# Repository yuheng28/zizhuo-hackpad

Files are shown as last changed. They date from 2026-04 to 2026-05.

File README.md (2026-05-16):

# ZizhuoPad

<p align="center">
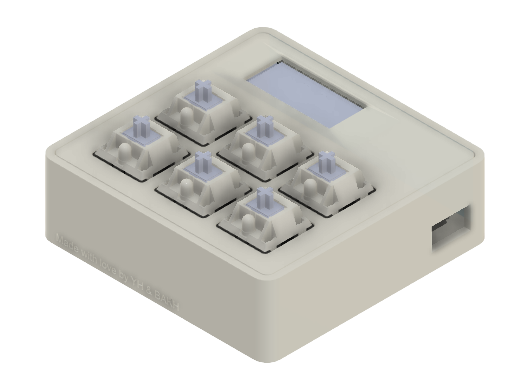
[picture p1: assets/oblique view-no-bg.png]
  
</p>

## Overview

ZizhuoPad is a custom mechanical macropad with 6 keys and an OLED display.

It is designed to allow for easy hotswapping of the switches, and (maybe not as easy) key mapping modifications.

## Rationale

This is a project to build a custom mechanical macropad. The purpose of this project is to create a birthday gift for my friend, after whom this project is named.

As a technical challenge, I opted to write the firmware using AVR-C, instead of using Arduino or QMK. The PCB was designed using KiCAD, and the case was designed using Fusion 360.

## Hardware Summary

### Electronics
- Microcontroller: SparkFun Pro Micro (ATmega32U4)
- OLED Display: 128x32 pixel display
- Switches: 6 hotswappable mechanical switches (Akko Piano Switches)
- Connector: USB-C

### Case
- Material: PETG
- Infill: 75%
- Walls: 10 for Case, 5 for Lid
- Layer Height: 0.2mm

## Modifying the Software

In the `firmware` directory, a Microchip Studio project is included. You can open the `.atsln` file in Microchip Studio to build the firmware.

The firmware uses the LUFA library to implement USB HID functionality. The project was first developed using the LUFA library's keyboard example, so as to have the build environment set up and working. Then, the code was modified to implement the desired functionality for the macropad.

However, since these are all in the project files, the build environment is already set up and working.

To modify the key mappings, lines 292-325 in Keyboard.c can be modified by replacing the keycode macros with the appropriate keycodes from LUFA's HID usage tables.

To modify the animation on the OLED display, the lines 65-135 in OLED.c can be modified with the appropriate bytes to display the desired animation. The OLED display has a resolution of 128x32 pixel display. To generate the byte array for the animation, use [Javl's image2cpp tool](https://javl.github.io/image2cpp/). The relevant settings for the tool are:
- Canvas Size: 128x32
- Orientation: Vertical
- Invert pixels: Yes (alternatively, line 191 in Keyboard.c can be commented to invert the pixels)

The other settings can be left as their default values. The generated byte array can then be copied into lines 292-325 in Keyboard.c.

After building the firmware, the resulting `Keyboard.hex` file can be flashed to the ATmega32U4 microcontroller using avrdude.

To flash the microcontroller, it needs to first be put into bootloader mode. This can be done by shorting the reset pin to ground. For approximately 8 seconds after doing this, the microcontroller will be in bootloader mode and can be flashed using avrdude.

## Project Pictures

<p align="center">
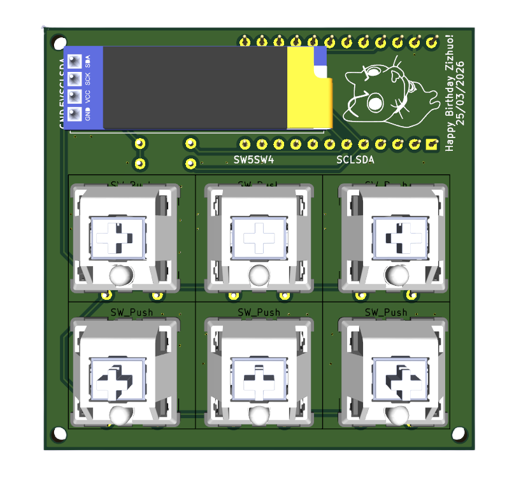
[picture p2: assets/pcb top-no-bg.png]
  
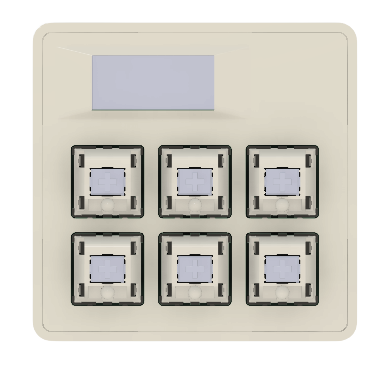
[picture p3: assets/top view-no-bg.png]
  
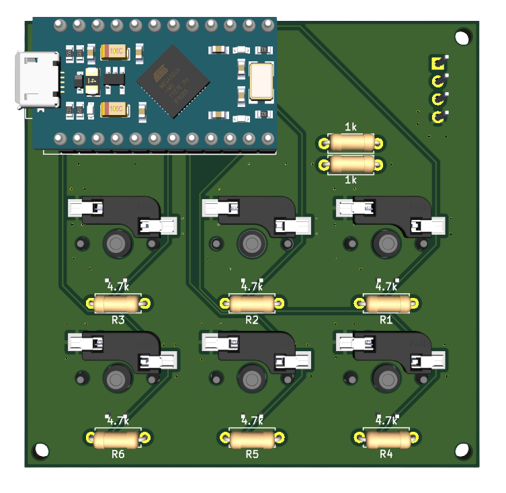
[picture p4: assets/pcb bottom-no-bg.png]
  
  
</p>

## Special Thanks

- [Boyce Ang Kok Hong (Hong Guo Feng)]() for helping with the design of the case, as well as providing help every step of the way.
- [HackClub](https://hackclub.com/) for inspiring this project
- [Javl's image2cpp tool](https://javl.github.io/image2cpp/) for generating the byte array for the OLED animation
- [LUFA library](https://www.fourwalledcubicle.com/LUFA.php) for providing the USB HID functionality
- [Sun Zizhuo](https://github.com/UnidentifiedX) for giving us a reason to make this project in the first place

## Bill of Materials
| **Name** | **Quantity** | **Price** | **Link** | **Distributor** |
|---|---|---|---|---|
| 3D Printed Case | 1 | 0 | | Additive Inn |
| USB C Cable | 1 | 0 | | Selleys |
| Gateron Hot-swappable Key Sockets | 6 | 0 | https://shopee.sg/10-pcs-Gateron-Hot-swappable-PCB-Socket-Mechanical-Keyboard-DIY-Hot-Plug-Socket-For-Cherry-MX-Switch-i.890923955.26713298801 | Shopee |
| Resistors (1k) | 2 | 0 | https://shopee.sg/1-PCS-or-10-PCS-of-Metal-Film-Resistors-1-4W-0.25W-1-10-Ohm-~1M-Ohm-Perintang-i.1361674071.27680985111 | Shopee |
| Resistors (4.7k) | 6 | 0 | https://shopee.sg/1-PCS-or-10-PCS-of-Metal-Film-Resistors-1-4W-0.25W-1-10-Ohm-~1M-Ohm-Perintang-i.1361674071.27680985111 | Shopee |
| 0.91" 128x32 OLED Display | 1 | 0 | https://shopee.sg/White-Blue-color-128X64-OLED-LCD-LED-Display-Module-For-Arduino-0.91-0.96-1.3-I2C-IIC-Serial-new-original-with-Case-i.365165105.8999544279 | Shopee |
| PCB | 1 | 0 | | JLCPCB |
| Akko Piano Switches | 6 | 0 | https://shopee.sg/-LINEAR-Akko-V3-Piano-Pro-45gf-Linear-Factory-Lubed-Mechanical-Switch-i.1344447555.27310390752 | Shopee |
| Sparkfun Pro Micro | 1 | 0 | https://shopee.sg/Pro-Micro-ATmega32U4-5V-16MHz-Replace-ATmega328-For-ATMega-32U4-Pro-Mini-With-2-Row-Pin-Header-i.517411014.23679394357 | Shopee |

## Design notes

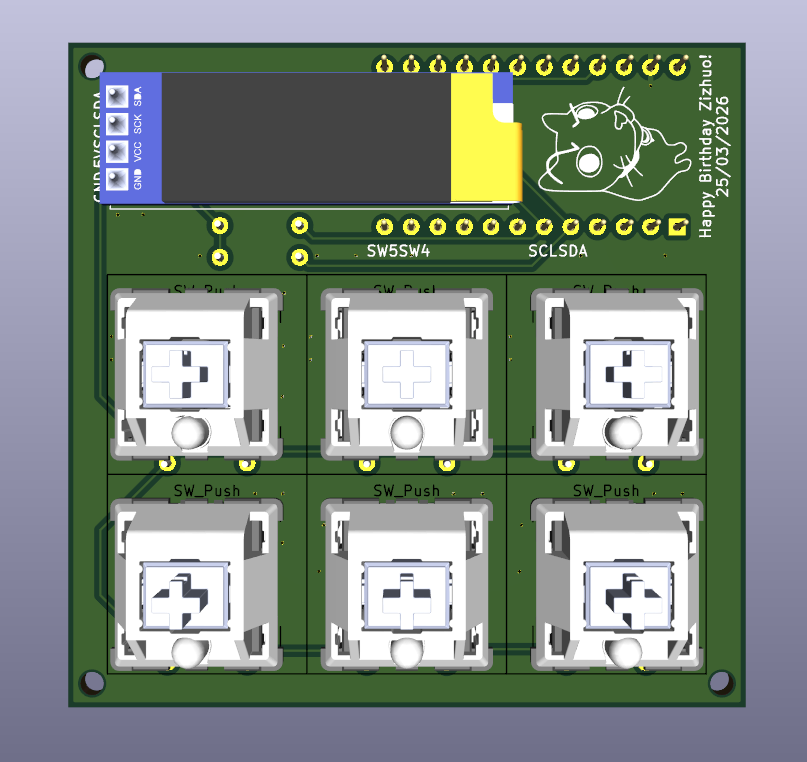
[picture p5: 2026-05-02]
assets/pcb top.png

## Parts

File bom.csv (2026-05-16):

Name | Purpose | Quantity | Total Cost (USD) | Link | Distributor
3D Printed Case | Case for the Macropad | 1 | 0 |  | Additive Inn
USB C Cable | To connect the keyboard to the computer | 1 | 0 |  | Selleys
Gateron Hot-swappable Key Sockets | To allow the switches to be easily swapped without the need for desoldering | 10 | 0 | https://shopee.sg/10-pcs-Gateron-Hot-swappable-PCB-Socket-Mechanical-Keyboard-DIY-Hot-Plug-Socket-For-Cherry-MX-Switch-i.890923955.26713298801 | Shopee
Resistors (1k) | Pullup resistors for i2c bus | 2 | 0 | https://shopee.sg/1-PCS-or-10-PCS-of-Metal-Film-Resistors-1-4W-0.25W-1-10-Ohm-~1M-Ohm-Perintang-i.1361674071.27680985111 | Shopee
Resistors (4.7k) | Pullup resistors for switch matrix | 6 | 0 | https://shopee.sg/1-PCS-or-10-PCS-of-Metal-Film-Resistors-1-4W-0.25W-1-10-Ohm-~1M-Ohm-Perintang-i.1361674071.27680985111 | Shopee
0.91" 128x32 OLED Display | To have a dynamic element on the keyboard | 1 | 0 | https://shopee.sg/White-Blue-color-128X64-OLED-LCD-LED-Display-Module-For-Arduino-0.91-0.96-1.3-I2C-IIC-Serial-new-original-with-Case-i.365165105.8999544279 | Shopee
PCB | To connect electrical parts | 1 | 0 |  | JLCPCB
Akko Piano Switches | Switches for the keyboard | 6 | 0 | https://shopee.sg/-LINEAR-Akko-V3-Piano-Pro-45gf-Linear-Factory-Lubed-Mechanical-Switch-i.1344447555.27310390752 | Shopee
Sparkfun Pro Micro | MCU | 1 | 0 | https://shopee.sg/Pro-Micro-ATmega32U4-5V-16MHz-Replace-ATmega328-For-ATMega-32U4-Pro-Mini-With-2-Row-Pin-Header-i.517411014.23679394357 | Shopee

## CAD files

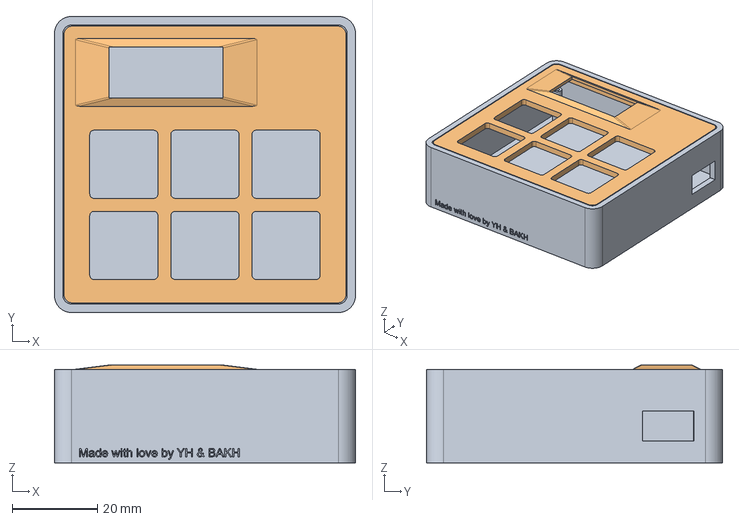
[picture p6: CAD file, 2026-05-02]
cad/macropad v3.3.step
70.7 x 69.5 x 23.0 mm

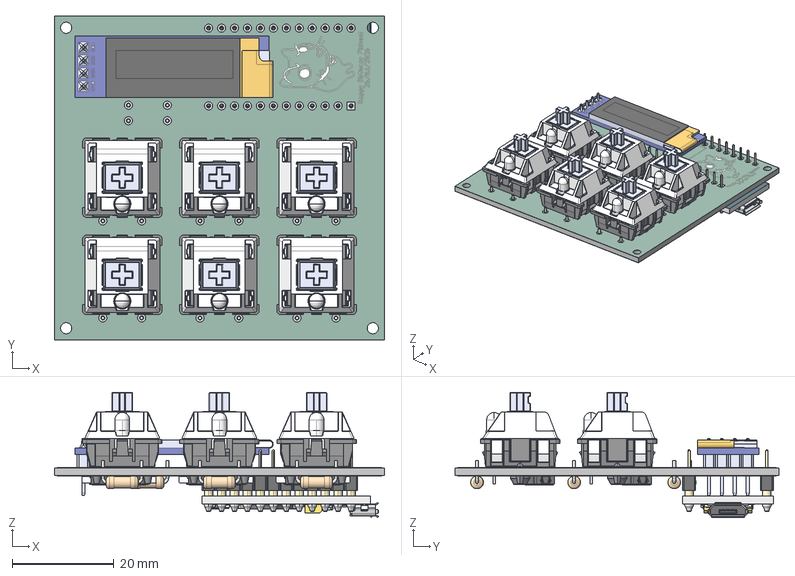
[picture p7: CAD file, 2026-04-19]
pcb/final macropad.step
64.7 x 63.5 x 24.5 mm
Contact x 12
Bottom x 6
Pulsador x 6
Top x 6
Pieza5^Cherry MX x 6
Pin1 x 6
Pin2 x 6
Led 3mm_trans x 6
0.91in OLED
micro board
MICRO_stackable header 12 x 2
MICRO_stackable header pin x 24
micro usb shell
micro usb internal
micro usb contact x 5
atmega32U4
MICRO_cap106C x 2
micro_crystal 5x3
micro_MIC5219
MICRO_603 resistor 103
MICRO_603 resistor 102
MICRO_603 resistor 22 x 2
MICRO_PTC-1206
MICRO_603 resistor 331 x 2
MICRO_603 cap on pad x 7
SOD 323
MICRO_led x 3
R_Axial_DIN0207_L6.3mm_D2.5mm_P7.62mm_Horizontal x 8
final macropad_copper
final macropad_pad
final macropad_via
final macropad_silkscreen x 2
final macropad_soldermask x 2
final macropad_PCB

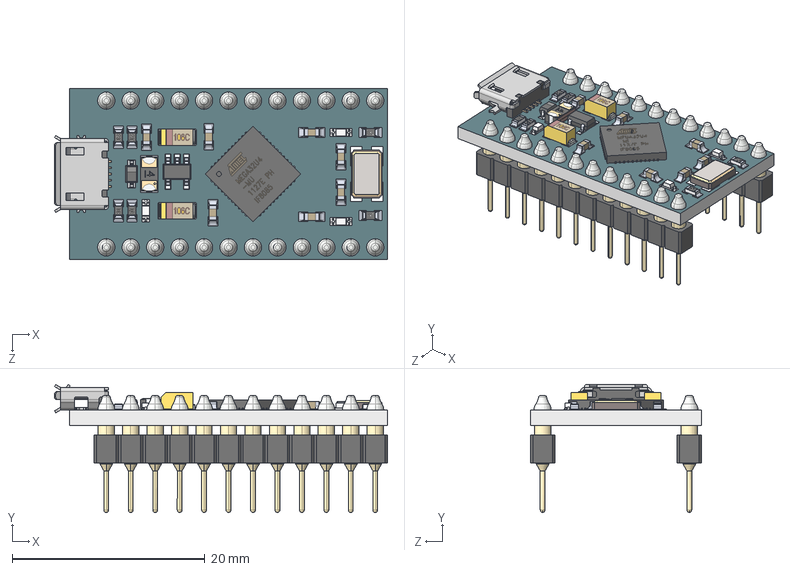
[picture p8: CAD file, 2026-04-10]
pcb/models/ARDUINO PRO MICRO.STEP
34.6 x 13.3 x 17.8 mm
micro board
MICRO_stackable header 12 x 2
MICRO_stackable header pin x 24
micro usb shell
micro usb internal
micro usb contact x 5
atmega32U4
MICRO_cap106C x 2
micro_crystal 5x3
micro_MIC5219
MICRO_603 resistor 103
MICRO_603 resistor 102
MICRO_603 resistor 22 x 2
MICRO_PTC-1206
MICRO_603 resistor 331 x 2
MICRO_603 cap on pad x 7
SOD 323
MICRO_led x 3

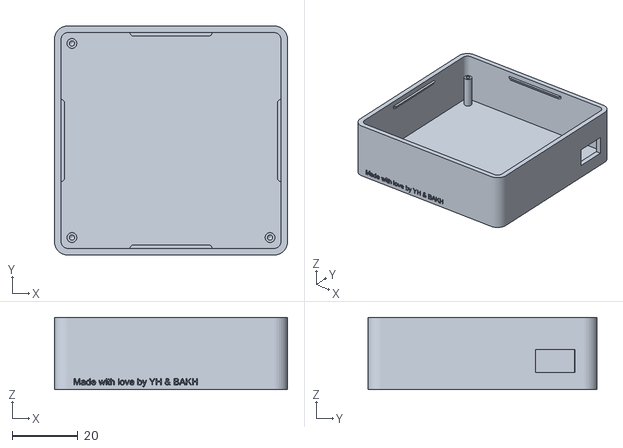
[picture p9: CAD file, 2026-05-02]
Production/case.stl
70.7 x 69.5 x 22.0

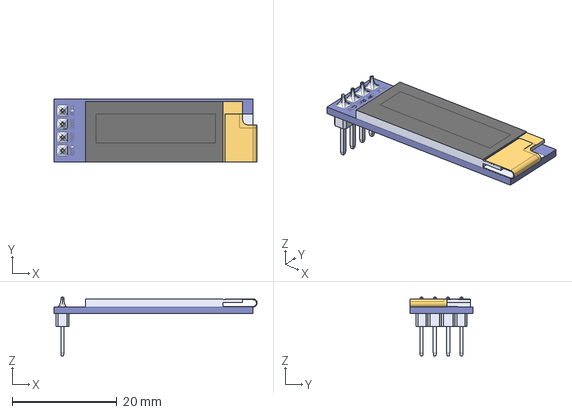
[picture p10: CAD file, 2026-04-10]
pcb/models/0.91in OLED.STEP
38.8 x 12.1 x 11.2 mm

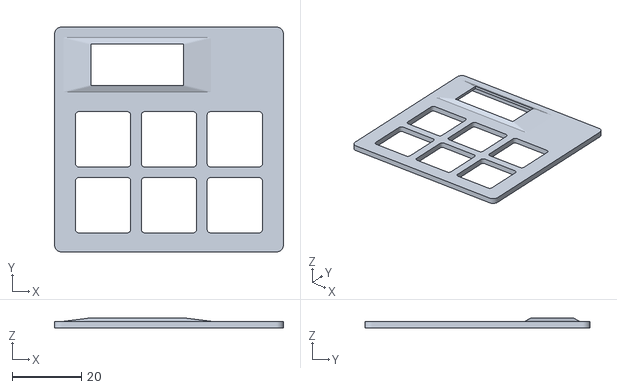
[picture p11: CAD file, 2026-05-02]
Production/cover.stl
66.2 x 65.0 x 3.00

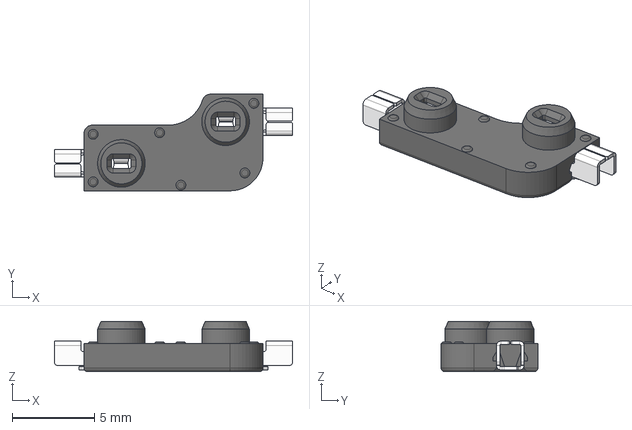
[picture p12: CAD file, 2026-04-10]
pcb/models/Kailh Hotswap.step
14.5 x 5.89 x 3.05 mm
Contact x 2

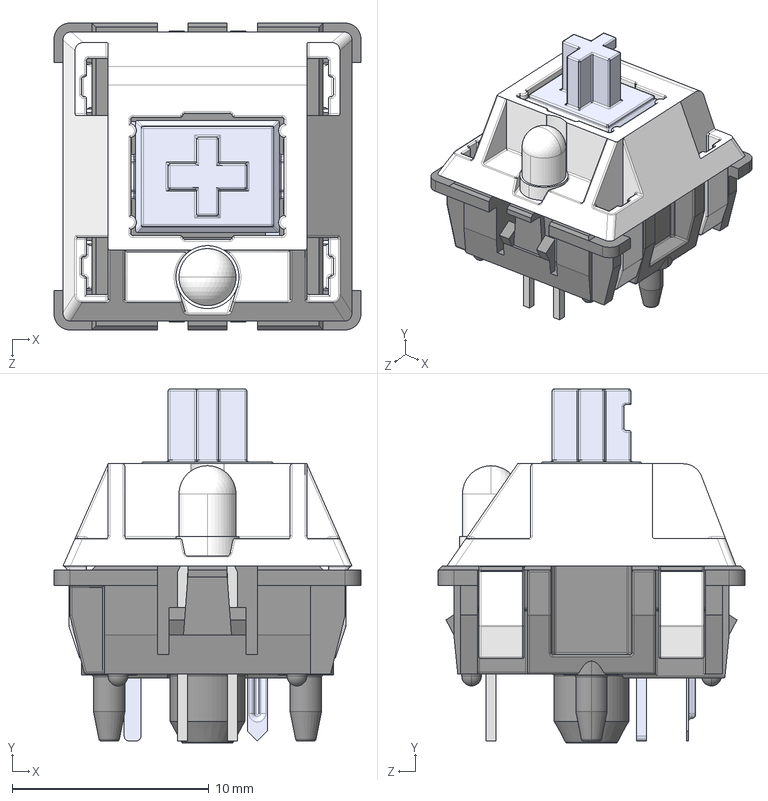
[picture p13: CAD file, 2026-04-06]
pcb/models/Cherry MX.STEP
15.6 x 18.0 x 15.6 mm
Bottom
Pulsador
Top
Pieza5^Cherry MX
Pin1
Pin2
Led 3mm_trans

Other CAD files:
cad/macropad v3.3.f3d

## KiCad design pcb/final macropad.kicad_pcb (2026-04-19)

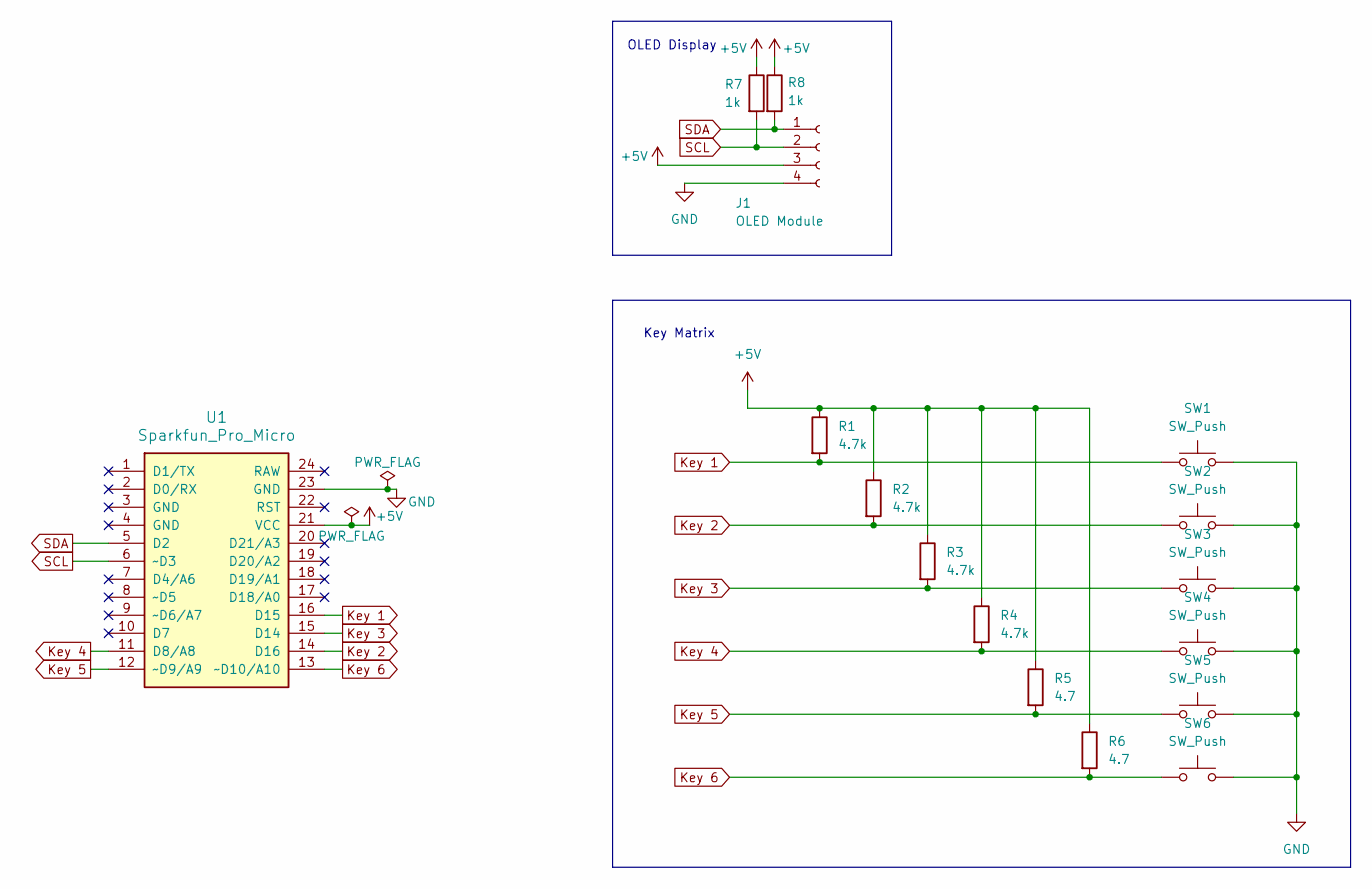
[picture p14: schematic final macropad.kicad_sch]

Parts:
J1: OLED Module; PinSocket_1x04_P2.54mm_Vertical
R1, R2, R3, R4: 4.7k; R_Axial_DIN0207_L6.3mm_D2.5mm_P7.62mm_Horizontal
R5, R6: 4.7; R_Axial_DIN0207_L6.3mm_D2.5mm_P7.62mm_Horizontal
R7, R8: 1k; R_Axial_DIN0207_L6.3mm_D2.5mm_P7.62mm_Horizontal
SW1, SW2, SW3, SW4, SW5, SW6: SW_Push; MXOnly-1U-Hotswap
U1: Sparkfun_Pro_Micro

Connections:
+5V: J1.3, R1.1, R2.1, R3.1, R4.1, R5.1, R6.1, R7.1, R8.1, U1.21 (VCC)
GND: J1.4, SW1.2, SW2.2, SW3.2, SW4.2, SW5.2, SW6.2, U1.23 (GND)
Key 1: R1.2, SW1.1, U1.16 (D15)
Key 2: R2.2, SW2.1, U1.14 (D16)
Key 3: R3.2, SW3.1, U1.15 (D14)
Key 4: R4.2, SW4.1, U1.11 (D8/A8)
Key 5: R5.2, SW5.1, U1.12 (~D9/A9)
Key 6: R6.2, SW6.1, U1.13 (~D10/A10)
SCL: J1.2, R7.2, U1.6 (~D3)
SDA: J1.1, R8.2, U1.5 (D2)

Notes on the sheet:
Key Matrix
OLED Display

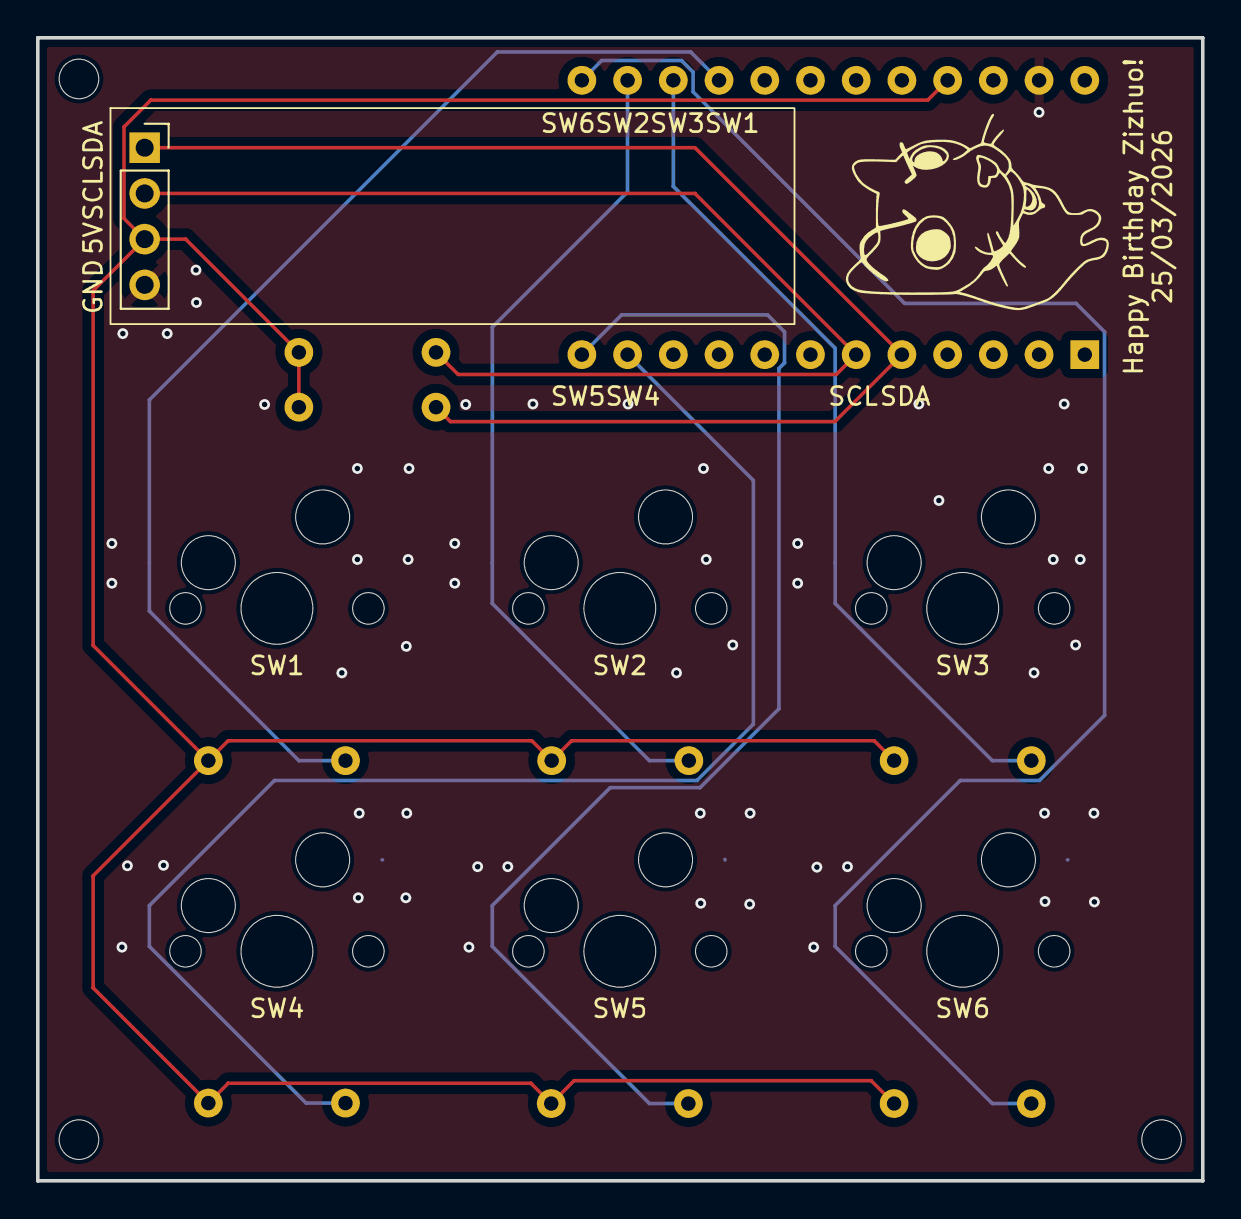
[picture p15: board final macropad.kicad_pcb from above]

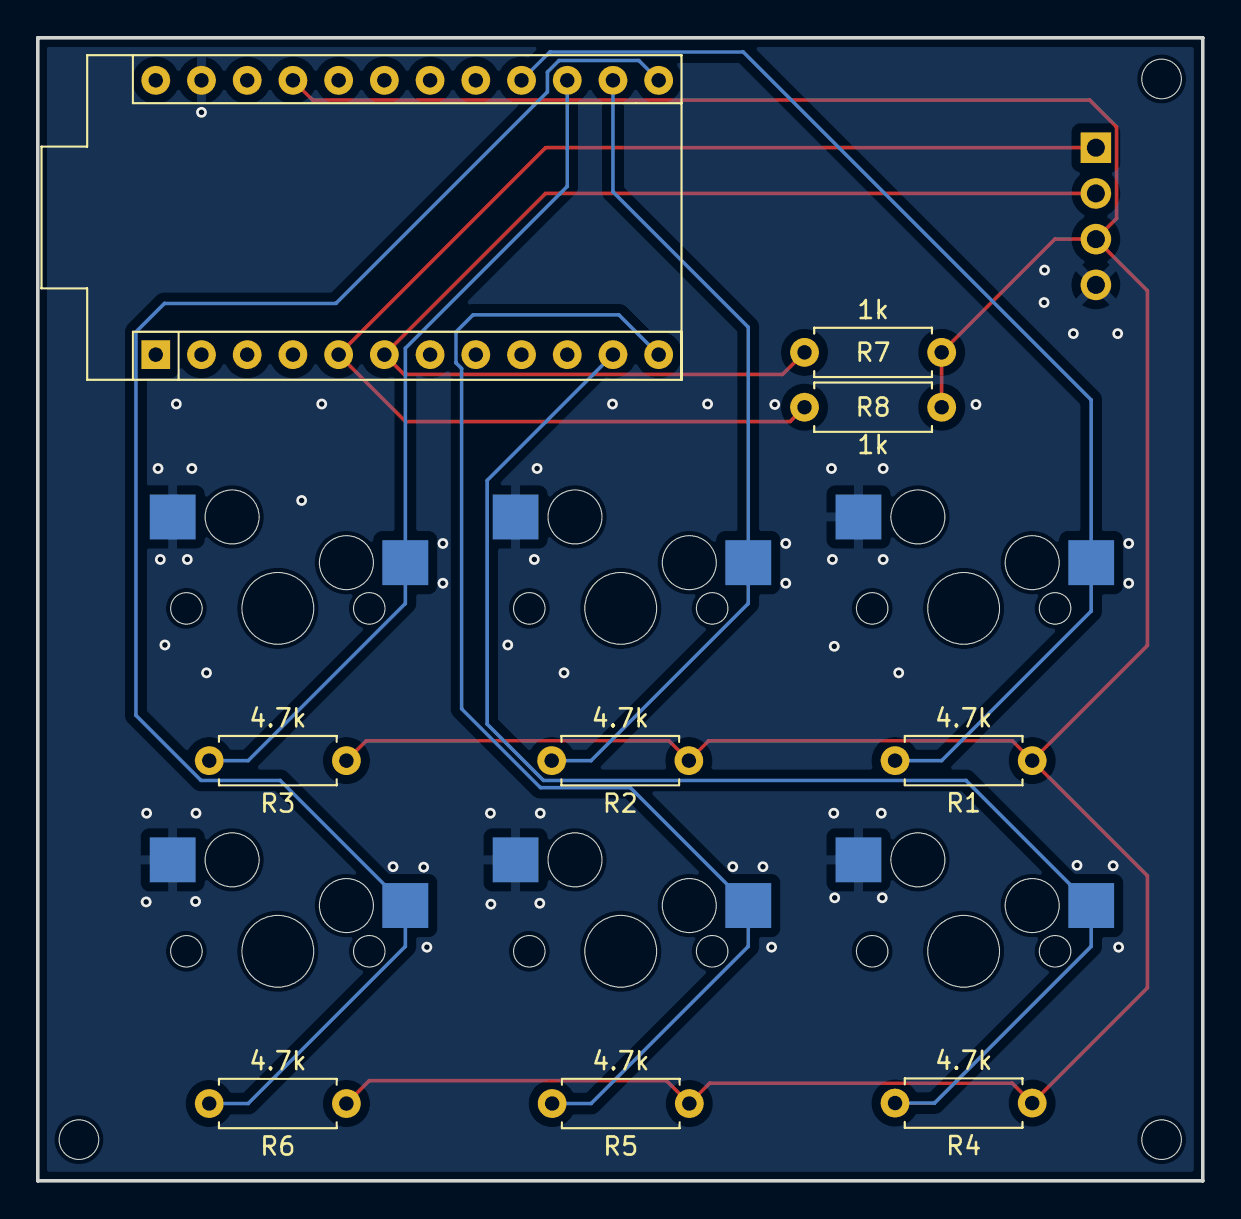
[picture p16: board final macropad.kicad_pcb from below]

Board: 2 copper layers, 64.7 x 63.5 mm, 16 parts (9 on the bottom side), 10 nets.

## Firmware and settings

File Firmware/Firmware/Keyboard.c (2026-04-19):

/*
             LUFA Library
     Copyright (C) Dean Camera, 2021.

  dean [at] fourwalledcubicle [dot] com
           www.lufa-lib.org
*/

/*
  Copyright 2021  Dean Camera (dean [at] fourwalledcubicle [dot] com)

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
  The author disclaims all warranties with regard to this
  software, including all implied warranties of merchantability
  and fitness.  In no event shall the author be liable for any
  special, indirect or consequential damages or any damages
  whatsoever resulting from loss of use, data or profits, whether
  in an action of contract, negligence or other tortious action,
  arising out of or in connection with the use or performance of
  this software.
*/

/** \file
 *
 *  Main source file for the Keyboard demo. This file contains the main tasks of
 *  the demo and is responsible for the initial application hardware configuration.
 */

#include "Keyboard.h"
#include "oled.h"

/** Buffer to hold the previously generated Keyboard HID report, for comparison purposes inside the HID class driver. */
static uint8_t PrevKeyboardHIDReportBuffer[sizeof(USB_KeyboardReport_Data_t)];

/** LUFA HID Class driver interface configuration and state information. This structure is
 *  passed to all HID Class driver functions, so that multiple instances of the same class
 *  within a device can be differentiated from one another.
 */
USB_ClassInfo_HID_Device_t Keyboard_HID_Interface =
	{
		.Config =
			{
				.InterfaceNumber              = INTERFACE_ID_Keyboard,
				.ReportINEndpoint             =
					{
						.Address              = KEYBOARD_EPADDR,
						.Size                 = KEYBOARD_EPSIZE,
						.Banks                = 1,
					},
				.PrevReportINBuffer           = PrevKeyboardHIDReportBuffer,
				.PrevReportINBufferSize       = sizeof(PrevKeyboardHIDReportBuffer),
			},
	};


// byte array of image
uint8_t frame_one[CACHE_SIZE] = 
{
	0xff, 0xff, 0xff, 0xff, 0xff, 0xff, 0xff, 0xff, 0xff, 0xff, 0xff, 0xff, 0xff, 0xff, 0xff, 0xff,
	0xff, 0xff, 0xff, 0xff, 0xff, 0xff, 0xff, 0xff, 0xff, 0xff, 0xff, 0xff, 0xff, 0xff, 0xff, 0xff,
	0xff, 0xff, 0xff, 0xff, 0xff, 0xff, 0xff, 0xff, 0xff, 0xff, 0xff, 0xff, 0xff, 0xff, 0xff, 0xff,
	0xff, 0xff, 0xff, 0xff, 0xff, 0xff, 0xff, 0xff, 0xff, 0xff, 0xff, 0xff, 0xff, 0xff, 0xff, 0xff,
	0xff, 0xff, 0xff, 0xff, 0xff, 0xff, 0xff, 0xff, 0xff, 0xff, 0xff, 0xff, 0xff, 0xff, 0xff, 0xff,
	0xff, 0xff, 0xff, 0xff, 0xff, 0xff, 0xff, 0xff, 0xff, 0xff, 0xff, 0xff, 0xff, 0xff, 0xff, 0xff,
	0xff, 0xff, 0xff, 0xff, 0xff, 0xff, 0xff, 0xff, 0xff, 0xff, 0xff, 0xff, 0xff, 0xff, 0xff, 0xff,
	0xff, 0xff, 0xff, 0xff, 0xff, 0xff, 0xff, 0xff, 0xff, 0xff, 0xff, 0xff, 0xff, 0xff, 0xff, 0xff,
	0xff, 0xff, 0xff, 0xff, 0xff, 0xff, 0xff, 0xff, 0xff, 0xff, 0xff, 0xff, 0xff, 0xff, 0xff, 0xff,
	0xff, 0xff, 0xff, 0xff, 0xff, 0xff, 0xff, 0xff, 0xff, 0xff, 0xff, 0xff, 0xff, 0xff, 0xff, 0xff,
	0xff, 0xff, 0xff, 0xff, 0xff, 0xff, 0xff, 0xff, 0xff, 0xff, 0xff, 0xff, 0xff, 0xff, 0xff, 0xff,
	0xff, 0xff, 0xff, 0x3f, 0x1f, 0x0f, 0x0f, 0x0f, 0x37, 0x03, 0x81, 0x80, 0x00, 0x01, 0x07, 0x07,
	0x07, 0x07, 0x0f, 0x0f, 0x0f, 0x0f, 0x1f, 0x1f, 0x1f, 0x0f, 0x0f, 0x0f, 0xff, 0xff, 0xff, 0xff,
	0xff, 0xff, 0xff, 0xff, 0xff, 0xff, 0xff, 0xff, 0xff, 0xff, 0xff, 0xff, 0xff, 0xff, 0xff, 0xff,
	0xff, 0xff, 0xff, 0xff, 0xff, 0xff, 0xff, 0xff, 0xff, 0xff, 0xff, 0xff, 0xff, 0xff, 0xff, 0xff,
	0xff, 0xff, 0xff, 0xff, 0xff, 0xff, 0xff, 0xff, 0xff, 0xff, 0xff, 0xff, 0xff, 0xff, 0xff, 0xff,
	0xff, 0xff, 0xff, 0xff, 0xff, 0xff, 0xff, 0xff, 0xff, 0xff, 0xff, 0xff, 0xff, 0xff, 0xff, 0xff,
	0xff, 0xff, 0xff, 0xff, 0xff, 0xff, 0xff, 0xff, 0xff, 0xff, 0xff, 0xff, 0xff, 0xff, 0xff, 0xff,
	0xff, 0xff, 0xff, 0xff, 0xff, 0xff, 0xff, 0xff, 0xff, 0xff, 0xff, 0xff, 0xff, 0xff, 0xff, 0xff,
	0xff, 0xff, 0xff, 0xf0, 0xf0, 0xf0, 0xe0, 0xe0, 0xe0, 0xe0, 0xe1, 0xe1, 0xc0, 0xc6, 0xc4, 0xc2,
	0xc4, 0xc8, 0xc8, 0x84, 0x80, 0x86, 0x86, 0xf8, 0x84, 0x82, 0x02, 0x02, 0x04, 0x19, 0xff, 0xff,
	0xff, 0xff, 0xff, 0xff, 0xff, 0xff, 0xff, 0xff, 0xff, 0xff, 0xff, 0xff, 0xff, 0xff, 0xff, 0xff,
	0xff, 0xff, 0xff, 0xff, 0xff, 0xff, 0xff, 0xff, 0xff, 0xff, 0xff, 0xff, 0xff, 0xff, 0xff, 0xff,
	0xff, 0xff, 0xff, 0xff, 0xff, 0xff, 0xff, 0xff, 0xff, 0xff, 0xff, 0xff, 0xff, 0xff, 0xff, 0xff,
	0xff, 0xff, 0xff, 0xff, 0xff, 0xff, 0xff, 0xff, 0xff, 0xff, 0xff, 0xff, 0xff, 0xff, 0xff, 0xff,
	0xff, 0xff, 0xff, 0xff, 0xff, 0xff, 0xff, 0xff, 0xff, 0xff, 0xff, 0xff, 0xff, 0xff, 0xff, 0xff,
	0xff, 0xff, 0xff, 0xff, 0xff, 0xff, 0xff, 0xff, 0xff, 0xff, 0xff, 0xff, 0xff, 0xff, 0xff, 0xff,
	0xff, 0xff, 0xff, 0xff, 0xff, 0xff, 0xff, 0xff, 0xff, 0xff, 0xff, 0xff, 0xff, 0xff, 0xff, 0xff,
	0xff, 0xff, 0xff, 0xff, 0xff, 0xff, 0xff, 0xff, 0xff, 0xff, 0xff, 0xff, 0xff, 0xff, 0xff, 0xff,
	0xff, 0xff, 0xff, 0xff, 0xff, 0xff, 0xff, 0xff, 0xff, 0xff, 0xff, 0xff, 0xff, 0xff, 0xff, 0xff,
	0xff, 0xff, 0xff, 0xff, 0xff, 0xff, 0xff, 0xff, 0xff, 0xff, 0xff, 0xff, 0xff, 0xff, 0xff, 0xff,
	0xff, 0xff, 0xff, 0xff, 0xff, 0xff, 0xff, 0xff, 0xff, 0xff, 0xff, 0xff, 0xff, 0xff, 0xff, 0xff
};

uint8_t frame_two[CACHE_SIZE] =
{
	0xff, 0xff, 0xff, 0xff, 0xff, 0xff, 0xff, 0xff, 0xff, 0xff, 0xff, 0xff, 0xff, 0xff, 0xff, 0xff,
	0xff, 0xff, 0xff, 0xff, 0xff, 0xff, 0xff, 0xff, 0xff, 0xff, 0xff, 0xff, 0xff, 0xff, 0xff, 0xff,
	0xff, 0xff, 0xff, 0xff, 0xff, 0xff, 0xff, 0xff, 0xff, 0xff, 0xff, 0xff, 0xff, 0xff, 0xff, 0xff,
	0xff, 0xff, 0xff, 0xff, 0xff, 0xff, 0xff, 0xff, 0xff, 0xff, 0xff, 0xff, 0xff, 0xff, 0xff, 0xff,
	0xff, 0xff, 0xff, 0xff, 0xff, 0xff, 0xff, 0xff, 0xff, 0xff, 0xff, 0xff, 0xff, 0xff, 0xff, 0xff,
	0xff, 0xff, 0xff, 0xff, 0xff, 0xff, 0xff, 0xff, 0xff, 0xff, 0xff, 0xff, 0xff, 0xff, 0xff, 0xff,
	0xff, 0xff, 0xff, 0xff, 0xff, 0xff, 0xff, 0xff, 0xff, 0xff, 0xff, 0xff, 0xff, 0xff, 0xff, 0xff,
	0xff, 0xff, 0xff, 0xff, 0xff, 0xff, 0xff, 0xff, 0xff, 0xff, 0xff, 0xff, 0xff, 0xff, 0xff, 0xff,
	0xff, 0xff, 0xff, 0xff, 0xff, 0xff, 0xff, 0xff, 0xff, 0xff, 0xff, 0xff, 0xff, 0xff, 0xff, 0xff,
	0xff, 0xff, 0xff, 0xff, 0xff, 0xff, 0xff, 0xff, 0xff, 0xff, 0xff, 0xff, 0xff, 0xff, 0xff, 0xff,
	0xff, 0xff, 0xff, 0xff, 0xff, 0xff, 0xff, 0xff, 0xff, 0xff, 0xff, 0xff, 0xff, 0xff, 0xff, 0xff,
	0xff, 0xff, 0xff, 0xff, 0xff, 0x3f, 0x1f, 0x0f, 0x07, 0x03, 0x81, 0x80, 0x00, 0x01, 0x07, 0x07,
	0x07, 0x07, 0x0f, 0x0f, 0x0f, 0x0f, 0x1f, 0x1f, 0x1f, 0x0f, 0x0f, 0x0f, 0xff, 0xff, 0xff, 0xff,
	0xff, 0xff, 0xff, 0xff, 0xff, 0xff, 0xff, 0xff, 0xff, 0xff, 0xff, 0xff, 0xff, 0xff, 0xff, 0xff,
	0xff, 0xff, 0xff, 0xff, 0xff, 0xff, 0xff, 0xff, 0xff, 0xff, 0xff, 0xff, 0xff, 0xff, 0xff, 0xff,
	0xff, 0xff, 0xff, 0xff, 0xff, 0xff, 0xff, 0xff, 0xff, 0xff, 0xff, 0xff, 0xff, 0xff, 0xff, 0xff,
	0xff, 0xff, 0xff, 0xff, 0xff, 0xff, 0xff, 0xff, 0xff, 0xff, 0xff, 0xff, 0xff, 0xff, 0xff, 0xff,
	0xff, 0xff, 0xff, 0xff, 0xff, 0xff, 0xff, 0xff, 0xff, 0xff, 0xff, 0xff, 0xff, 0xff, 0xff, 0xff,
	0xff, 0xff, 0xff, 0xff, 0xff, 0xff, 0xff, 0xff, 0xff, 0xff, 0xff, 0xff, 0xff, 0xff, 0xff, 0xff,
	0xff, 0xff, 0xbf, 0xe3, 0xc0, 0xc0, 0xc0, 0xe0, 0xe0, 0xf0, 0xe1, 0xe1, 0xc0, 0xc6, 0xc4, 0xc2,
	0xc4, 0xc8, 0xc8, 0x84, 0xc0, 0x26, 0x06, 0x00, 0x00, 0x00, 0x00, 0x00, 0x00, 0x01, 0xff, 0xff,
	0xff, 0xff, 0xff, 0xff, 0xff, 0xff, 0xff, 0xff, 0xff, 0xff, 0xff, 0xff, 0xff, 0xff, 0xff, 0xff,
	0xff, 0xff, 0xff, 0xff, 0xff, 0xff, 0xff, 0xff, 0xff, 0xff, 0xff, 0xff, 0xff, 0xff, 0xff, 0xff,
	0xff, 0xff, 0xff, 0xff, 0xff, 0xff, 0xff, 0xff, 0xff, 0xff, 0xff, 0xff, 0xff, 0xff, 0xff, 0xff,
	0xff, 0xff, 0xff, 0xff, 0xff, 0xff, 0xff, 0xff, 0xff, 0xff, 0xff, 0xff, 0xff, 0xff, 0xff, 0xff,
	0xff, 0xff, 0xff, 0xff, 0xff, 0xff, 0xff, 0xff, 0xff, 0xff, 0xff, 0xff, 0xff, 0xff, 0xff, 0xff,
	0xff, 0xff, 0xff, 0xff, 0xff, 0xff, 0xff, 0xff, 0xff, 0xff, 0xff, 0xff, 0xff, 0xff, 0xff, 0xff,
	0xff, 0xff, 0xfd, 0xfe, 0xff, 0xff, 0xfc, 0xff, 0xff, 0xff, 0xff, 0xff, 0xff, 0xff, 0xff, 0xff,
	0xfd, 0xfd, 0xf7, 0xff, 0xfc, 0xfc, 0xf4, 0xfc, 0xfc, 0xfe, 0xfe, 0xff, 0xff, 0xff, 0xff, 0xff,
	0xff, 0xff, 0xff, 0xff, 0xff, 0xff, 0xff, 0xff, 0xff, 0xff, 0xff, 0xff, 0xff, 0xff, 0xff, 0xff,
	0xff, 0xff, 0xff, 0xff, 0xff, 0xff, 0xff, 0xff, 0xff, 0xff, 0xff, 0xff, 0xff, 0xff, 0xff, 0xff,
	0xff, 0xff, 0xff, 0xff, 0xff, 0xff, 0xff, 0xff, 0xff, 0xff, 0xff, 0xff, 0xff, 0xff, 0xff, 0xff
};

void paw_down() {
	oled_start_update(frame_two);
}

void paw_up() {
	oled_start_update(frame_one);
}

typedef enum {
	PAW_UP,
	PAW_DOWN
} paw_state_t;

volatile paw_state_t paw_state = PAW_UP;
volatile uint16_t paw_timer_in_ms = 0;

/** Main program entry point. This routine contains the overall program flow, including initial
 *  setup of all components and the main program loop.
 */
int main(void)
{	
	// memset(frame_one, 0xff, sizeof(frame_one));
	//DDRB = 0x00;
	//PORTB = 0xFF;
	//
	//i2c_init();
	//oled_init();
	//_delay_ms(100);
	//
	//while (1) {
		//i2c_reset();
		//oled_set_addressing(0,0);
		////i2c_reset();
		//oled_update_ram(frame_one);
		//_delay_ms(250);
		////i2c_reset();
		//oled_set_addressing(0,0);
		////i2c_reset();
		//oled_update_ram(frame_two);
		//_delay_ms(250);
	//};
	
	
	SetupHardware();
	GlobalInterruptEnable();
	
	DDRB = 0x00;
	PORTB = 0xFF;
	
	i2c_init();
	oled_init();
	_delay_ms(100);
	
	// set first frame
	oled_inverse_screen();
	oled_update_ram(frame_one);

	static uint8_t last_frame = 0;

	for (;;)
	{
		HID_Device_USBTask(&Keyboard_HID_Interface);
		USB_USBTask();
		
		oled_update_step();
		
		if (paw_state ==  PAW_DOWN && last_frame != 1 && !oled_busy) {
			paw_down();
			last_frame = 1;
		}
		else if (paw_state ==  PAW_UP && last_frame != 0 && !oled_busy) {
			paw_up();
			last_frame = 0;
		}
	}
}

/** Configures the board hardware and chip peripherals for the demo's functionality. */
void SetupHardware()
{
#if (ARCH == ARCH_AVR8)
	/* Disable watchdog if enabled by bootloader/fuses */
	MCUSR &= ~(1 << WDRF);
	wdt_disable();

	/* Disable clock division */
	clock_prescale_set(clock_div_1);
#elif (ARCH == ARCH_XMEGA)
	/* Start the PLL to multiply the 2MHz RC oscillator to 32MHz and switch the CPU core to run from it */
	XMEGACLK_StartPLL(CLOCK_SRC_INT_RC2MHZ, 2000000, F_CPU);
	XMEGACLK_SetCPUClockSource(CLOCK_SRC_PLL);

	/* Start the 32MHz internal RC oscillator and start the DFLL to increase it to 48MHz using the USB SOF as a reference */
	XMEGACLK_StartInternalOscillator(CLOCK_SRC_INT_RC32MHZ);
	XMEGACLK_StartDFLL(CLOCK_SRC_INT_RC32MHZ, DFLL_REF_INT_USBSOF, F_USB);

	PMIC.CTRL = PMIC_LOLVLEN_bm | PMIC_MEDLVLEN_bm | PMIC_HILVLEN_bm;
#endif

	/* Hardware Initialization */
	USB_Init();
}

/** Event handler for the library USB Configuration Changed event. */
void EVENT_USB_Device_ConfigurationChanged(void)
{
	bool ConfigSuccess = true;

	ConfigSuccess &= HID_Device_ConfigureEndpoints(&Keyboard_HID_Interface);

	USB_Device_EnableSOFEvents();

	//LEDs_SetAllLEDs(ConfigSuccess ? LEDMASK_USB_READY : LEDMASK_USB_ERROR);
}

/** Event handler for the library USB Control Request reception event. */
void EVENT_USB_Device_ControlRequest(void)
{
	HID_Device_ProcessControlRequest(&Keyboard_HID_Interface);
}

/** Event handler for the USB device Start Of Frame event. */
void EVENT_USB_Device_StartOfFrame(void)
{
	HID_Device_MillisecondElapsed(&Keyboard_HID_Interface);
	
	// update paw_timer
	if (paw_timer_in_ms > 0) paw_timer_in_ms--;
	
	if (paw_timer_in_ms == 0 && paw_state == PAW_DOWN) paw_state = PAW_UP;
}

/** HID class driver callback function for the creation of HID reports to the host.
 *
 *  \param[in]     HIDInterfaceInfo  Pointer to the HID class interface configuration structure being referenced
 *  \param[in,out] ReportID    Report ID requested by the host if non-zero, otherwise callback should set to the generated report ID
 *  \param[in]     ReportType  Type of the report to create, either HID_REPORT_ITEM_In or HID_REPORT_ITEM_Feature
 *  \param[out]    ReportData  Pointer to a buffer where the created report should be stored
 *  \param[out]    ReportSize  Number of bytes written in the report (or zero if no report is to be sent)
 *
 *  \return Boolean \c true to force the sending of the report, \c false to let the library determine if it needs to be sent
 */
bool CALLBACK_HID_Device_CreateHIDReport(USB_ClassInfo_HID_Device_t* const HIDInterfaceInfo,
                                         uint8_t* const ReportID,
                                         const uint8_t ReportType,
                                         void* ReportData,
                                         uint16_t* const ReportSize)
{
	USB_KeyboardReport_Data_t* KeyboardReport = (USB_KeyboardReport_Data_t*)ReportData;

	memset(KeyboardReport, 0, sizeof(USB_KeyboardReport_Data_t));

	uint8_t UsedKeyCodes = 0;
	bool key_pressed = false;
	
	if(!(PINB&(1<<PB1))) {
		key_pressed = true;
		KeyboardReport->KeyCode[UsedKeyCodes++] = HID_KEYBOARD_SC_1_AND_EXCLAMATION;
	}
	
	if(!(PINB&(1<<PB2))) {
		key_pressed = true;
		KeyboardReport->KeyCode[UsedKeyCodes++] = HID_KEYBOARD_SC_2_AND_AT;
	}
	
	if(!(PINB&(1<<PB3))) {
		key_pressed = true;
		KeyboardReport->KeyCode[UsedKeyCodes++] = HID_KEYBOARD_SC_3_AND_HASHMARK;
	}
	
	if(!(PINB&(1<<PB4))) {
		key_pressed = true;
		KeyboardReport->KeyCode[UsedKeyCodes++] = HID_KEYBOARD_SC_4_AND_DOLLAR;
	}
	
	if(!(PINB&(1<<PB5))) {
		key_pressed = true;
		KeyboardReport->KeyCode[UsedKeyCodes++] = HID_KEYBOARD_SC_5_AND_PERCENTAGE;
	}
	
	if(!(PINB&(1<<PB6))) {
		key_pressed = true;
		KeyboardReport->KeyCode[UsedKeyCodes++] = HID_KEYBOARD_SC_6_AND_CARET;
	}
	
	if (key_pressed) {
		paw_state = PAW_DOWN;
		paw_timer_in_ms = PAW_DOWN_TIME_MS;
	}

	*ReportSize = sizeof(USB_KeyboardReport_Data_t);
	return false;
}

void CALLBACK_HID_Device_ProcessHIDReport(USB_ClassInfo_HID_Device_t* const HIDInterfaceInfo,
                                          const uint8_t ReportID,
                                          const uint8_t ReportType,
                                          const void* ReportData,
                                          const uint16_t ReportSize)
{
	// none used, but LUFA requires this to be defined.
}

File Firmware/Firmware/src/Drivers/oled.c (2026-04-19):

/*
 * oled.c
 *
 * Created: 13/4/2026 11:28:37 pm
 *  Author: Yu Heng
 */ 

#include <avr/io.h>
#include <stddef.h>
#include <avr/delay.h>
#include "oled.h"

void oled_init() {
	i2c_send_start();
	i2c_enter_MT_mode(OLED_ADDR);

	i2c_send(0x00); // command mode

	i2c_send(0xAE); // display OFF
	i2c_send(0xD5); i2c_send(0x80);
	i2c_send(0xA8); i2c_send(0x1F);
	i2c_send(0xD3); i2c_send(0x00);
	i2c_send(0x40);
	i2c_send(0x8D); i2c_send(0x14); // charge pump ON
	i2c_send(0x20); i2c_send(0x00); // horizontal addressing mode
	i2c_send(0xA1);
	i2c_send(0xC8);
	i2c_send(0xDA); i2c_send(0x02);
	i2c_send(0x81); i2c_send(0x7F);
	i2c_send(0xA4);
	i2c_send(0xA6);
	i2c_send(0xAF); // display ON

	i2c_send_stop();
}

void oled_inverse_screen() {
	i2c_send_start();
	i2c_enter_MT_mode(OLED_ADDR);
	i2c_send(0x00); // Co = 0, D/C# = 0 (command)
	i2c_send(0xA7); // entire screen on
	i2c_send_stop();
}

void oled_turn_on() {
	i2c_send_start();
	i2c_enter_MT_mode(OLED_ADDR);
	i2c_send(0x00); // Co = 0, D/C# = 0 (command)
	i2c_send(0xA5); // entire screen on
	i2c_send_stop();
}

void oled_turn_off() {
	i2c_send_start();
	i2c_enter_MT_mode(OLED_ADDR);
	i2c_send(0x00); // Co = 0, D/C# = 0 (command)
	i2c_send(0xA4); // disable entire screen on
	i2c_send_stop();
}

void oled_set_addressing(uint8_t start_col, uint8_t start_page) {
	i2c_send_start();
	i2c_enter_MT_mode(OLED_ADDR);
	i2c_send(0x00);

	i2c_send(0x21); // column address
	i2c_send(start_col); // start column
	i2c_send(0x7F); // end column

	i2c_send(0x22); // page address
	i2c_send(start_page); // start page
	i2c_send(0x03); // end page (32px display)

	i2c_send_stop();
}

static uint16_t oled_index = 0;
static uint8_t *oled_buf = NULL;
volatile uint8_t oled_busy = 0;

void oled_start_update(uint8_t *arr) {
	if (oled_busy) return;

	oled_buf = arr;
	oled_index = 0;
	oled_busy = 1;
	
	oled_set_addressing(0, 0);
}

void oled_update_step() {
	if (!oled_busy) return;

	// First call ? send header
	//if (oled_index == 0) {
		//
	//}
	
	// Send a small chunk per call
	uint8_t chunk = 128;  // ?? should be multiple of 8 and factor of 64

	//oled_set_addressing(oled_index % 128, (oled_index / 128)); // columns are 128 pixels, each page is 8 rows. / takes floor for integers

	i2c_send_start();
	i2c_enter_MT_mode(OLED_ADDR);
	i2c_send(0x40); // data mode

	for (uint8_t i = 0; i < chunk && oled_index < CACHE_SIZE; i++) {
		i2c_send(oled_buf[oled_index++]);
		USB_USBTask();
	}
	i2c_send_stop();

	// Done
	if (oled_index >= CACHE_SIZE) {
		oled_busy = 0;
	}
}

void oled_update_ram(uint8_t *arr) {
	oled_set_addressing(0, 0);
	i2c_send_start();
	i2c_enter_MT_mode(OLED_ADDR);
	i2c_send(0x40); // Co = 0, D/C# = 1 (data)
	
	uint16_t i = 0;
	while (i < CACHE_SIZE) {
		i2c_send(arr[i++]);
	}
	
	i2c_send_stop();
}

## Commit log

2026-04-06 replaced footprints of switches, routed pcb
    [final macropad.kicad_pcb, final macropad.kicad_sch]
2026-04-10 Added models
    [0.91in OLED.STEP, ARDUINO PRO MICRO.STEP, Kailh Hotswap.step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]
2026-04-10 redesigned PCB, added silkscreen
    [final macropad.kicad_pcb]
2026-04-11 Added firmware
    [final macropad.step]
2026-04-13 updated pcb
    [final macropad.kicad_pcb, final macropad.step]
2026-04-13 updated pcb, removed old firmware from tracking
    [final macropad.kicad_pcb]
2026-04-14 finished oled drivers
2026-04-15 working on firmware, i2c does not want to work nicely with the usb process
2026-04-16 finished up firmware
    [final macropad.kicad_pcb, final macropad.kicad_sch, final macropad.step]
2026-04-19 changed the display to run as a 128x32 display instead. Inverted colours
    [final macropad.step]
2026-04-19 added gerber files
    [final macropad-B_Cu.gbl, final macropad-B_Mask.gbs, final macropad-B_Paste.gbp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]
2026-04-21 updated drawing sheet
    [final macropad.kicad_sch]
2026-05-02 final additions
    [bom.csv, case.stl, cover.stl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]
2026-05-16 forgot to include the price in the bom
    [bom.csv]
